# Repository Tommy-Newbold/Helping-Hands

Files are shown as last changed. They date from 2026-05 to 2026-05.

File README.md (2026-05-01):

Helping Hands are interactive public sculptures that invite people to listen to local stories about climate-adapted futures.

---

helping hands wordmark



---

Each hand senses when it is touched, glows with light, and plays an audio story. The project began as part of *Waters of Leith*, a design project exploring how local knowledge, everyday experience, and public imagination can shape climate adaptation in Leith, Edinburgh.

This repository contains the files needed to make your own Helping Hand: 3D-printable parts, casting tools, wiring notes, firmware, and installation guidance.

---

## What are Helping Hands?

Helping Hands are small, touch-sensitive audio sculptures designed to be installed in public or semi-public places.



They act as **waymarkers**: physical points where community stories, memories, concerns, and hopes can be held, heard, and shared.

When someone holds a hand, it responds with light and sound. Each hand can contain a different voice, story, or message from the future.

---

## Why make them?

Helping Hands are about making local imagination tangible.

They can be used for:

- community engagement
- speculative design workshops
- climate adaptation conversations
- public art installations
- local storytelling projects
- education and participatory research
- playful civic experiments

The project is intentionally open-ended. You can build one as a sculpture, a workshop output, a public installation, or a starting point for your own version.

---

## Features

Tommy chat - 2026-05-01 06 41 29

Current and planned firmware features:

- [x] MicroPython firmware
- [x] Touch sensing
- [x] Audio playback using the JQ6500 MP3 module
- [x] Blue LED pulse when touched
- [x] Direct touch trigger
- [x] Near-sense trigger mode
- [x] Access Point monitor dashboard
- [x] Touch logging
- [x] Touch duration logging
- [x] Day/night behaviour
- [x] Quiet hours
- [x] Optional RTC support for reliable timekeeping
- [ ] Mesh mode for linking multiple hands together
- [ ] Windows/Linux install wizard
- [ ] Improved dashboarding
- [ ] Remote access
- [ ] USB-C battery-management routing
- [ ] Lower-cost electronics version
- [ ] More confirmed print profiles

Confirmed print testing:

- [x] Bambu Lab A1 Mini
- [x] Bambu Lab P1S
- [x] Creality Ender 3
- [ ] More printers wanted!

---

## Overall instructions

Tommy chat - 2026-05-01 06 41 34

The basic build process is:

1. Buy the electronic components.
2. Print the enclosure and internal parts.
3. Cast the hands.
4. Wire the electronics.
5. Flash the ESP32 with MicroPython.
6. Upload the Helping Hands firmware.
7. Add your audio files to the JQ6500 module.
8. Configure the hand.
9. Test touch, audio, lights, and power.
10. Install the hand.

For the full build guide, see:

[`docs/instructions.md`](docs/instructions.md)

For print settings and tuning, see:

[`docs/3d-printing.md`](docs/3d-printing.md)

For enclosure customisation, see:

[`docs/enclosure-customisation.md`](docs/enclosure-customisation.md)

---

## Tools

You will likely need:

- 3D printer
- Soldering iron
- laptop or desktop computer

---

# Parts list

## 3D prints

The printable files are split into a few sets:

| Print set | Description | Link |
|---|---|---|
| Enclosure | Main body, lid, mounts, internal structure |  |
| PCB / wiring carrier | Printable wiring support or internal carrier |  |
| Hand casting tool | Tools for aligning threaded rod and casting hands | |

More detail:

[`docs/3d-printing.md`](docs/3d-printing.md)

---

## Components
For full list see: 

[`docs/shopping-list.md`](docs/shopping-list.md)

### Electronics

| Part | Notes | Link |
|---|---|---|
| ESP32 WROOM dev board | Main controller | Link coming soon |
| JQ6500 MP3 player | Audio playback module | Link coming soon |
| Adafruit BQ25185 solar charger | For solar installs | Adafruit link coming soon |
| DS3231 RTC module | Optional, improves day/night and quiet-hour reliability | Link coming soon |
| 18650 Li-ion cell | Use a reputable protected cell where possible | Link coming soon |
| 3W 8Ω 67mm speaker driver | Main audio output | Link coming soon |
| 24 LED COB WS2812B Light Ring | Light feedback | Adafruit / cheap link coming soon |

---

# Firmware

The firmware is written in MicroPython.

Current files include:

| File | Description |
|---|---|
| `main.py` | Main Helping Hands firmware |
| `jq6500.py` | JQ6500 MP3 player library |
| `rtc_flash.py` | RTC setup / flashing helper |
| `config.py.example` | Example configuration file |

---

# Customisation

This project is meant to be messed with. You can customise:

- enclosure form
- textures and surface details
- light behaviour
- timing
- audio content
- installation context
- overall theme

See:

[`docs/enclosure-customisation.md`](docs/enclosure-customisation.md)

---

# Installation

Helping Hands can be installed indoors, outdoors, or as part of temporary public engagement events.

Before installing in public, consider:

- permission from the site owner
- weather protection
- safe mounting
- battery access
- charging method
- audio volume
- trip hazards
- sharp edges
- vandal resistance
- how people will know what to do
- whether the hand needs a plaque, label, or prompt

Suggested prompt:

> Hold my hand. Hear my story.

---

# Documentation

Planned documentation:

| Document | Status |
|---|---|
| `docs/instructions.md` | In progress |
| `docs/3d-printing.md` | In progress |
| `docs/wiring.md` | In progress |
| `docs/firmware.md` | In progress |
| `docs/enclosure-customisation.md` | In progress |
| `docs/casting.md` | In progress |
| `docs/installing.md` | In progress |
| `docs/troubleshooting.md` | In progress |

---

# Troubleshooting

Common issues currently include:

| Problem | Likely cause |
|---|---|
| Touch works on USB but not battery | Weak ground reference or touch threshold needs tuning |
| LEDs do not turn on | Power issue, wrong data pin, or insufficient current |
| Audio does not play | JQ6500 file indexing or wiring issue |
| Time-based features are wrong | RTC not set or missing |
| Dashboard does not appear | ESP32 AP mode not active |
| Touch is too sensitive | Threshold too low |
| Touch is not sensitive enough | Threshold too high or poor touch connection |

See:

[`docs/troubleshooting.md`](docs/troubleshooting.md)

---

# Roadmap

Things I would like to improve next:

- [ ] Better installation wizard
- [ ] Cleaner dashboard UI
- [ ] Mesh behaviour between multiple hands
- [ ] Easier audio upload process
- [ ] Better battery monitoring
- [ ] More reliable solar version
- [ ] Cheaper electronics version
- [ ] More enclosure variants
- [ ] More mounting options
- [ ] More print profiles from different printers
- [ ] Better documentation for public installs

---

# Contributing

Please contribute!

This project is still developing, and there are lots of ways to help:

- build your own version
- share photos of your installation
- test the print files on different printers
- suggest better components
- improve the firmware
- report bugs
- improve the documentation
- make new enclosure variants
- adapt the project for another place or community

If something does not work, open an issue and describe:

1. what you were trying to do
2. what happened
3. what hardware you used
4. what firmware version you used
5. photos or screenshots if useful

Pull requests are welcome, especially for small fixes, documentation improvements, and tested hardware changes.

Forks, remixes, and strange versions are encouraged.

---

# Credits

Created by **Tommy Newbold / Studio Tommy** as part of the *Waters of Leith* project.

This project uses the `jq6500.py` library for controlling the JQ6500 MP3 module.

Credit and source link to be added.

---

# Licensing

This project uses separate licences for code and physical/documentation files.

1. **Code:** Licensed under [GPLv3](https://www.gnu.org/licenses/gpl-3.0.html).
2. **3D Models and Documentation:** Licensed under [CC-BY-SA 4.0](https://creativecommons.org/licenses/by-sa/4.0/).

This means you can use, adapt, remix, and share the project, but improvements should remain open and credited.

---

# A note on AI-assisted code

Some of the firmware and documentation for this project has been developed with the help of AI coding tools.

That means the code should be treated like any other experimental open-source hardware project: useful, hackable, and worth checking carefully before relying on it.

If you spot something odd, inefficient, unsafe, or just badly explained, please open an issue or suggest an improvement.

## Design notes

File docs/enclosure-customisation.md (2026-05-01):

# Enclosure Customisation

This guide covers simple ways to customise the Helping Hands enclosure, from surface decoration and painting to adding custom texture using displacement tools.

The enclosure has been designed to be adaptable. You can keep it plain, paint it, decorate it for a specific project, or generate a textured version for a more site-specific build.

---

## Quick overview

Common customisation options include:

- Painting the enclosure
- Adding project-specific decoration
- Using coloured or translucent filament
- Adding vinyl graphics or labels
- Adding physical props or attachments
- Applying custom surface texture with displacement

For the main build guide, see:

[`docs/instructions.md`](./instructions.md)

For print settings, see:

[`docs/3d-printing.md`](./3d-printing.md)

---

<details open>
<summary><strong>1. Simple decoration</strong></summary>

## 1. Simple decoration

The simplest way to customise the enclosure is through decoration.

For example, in the original urban flooding project, the enclosure was styled with visual references to **life rings**, public safety equipment, and civic infrastructure.

### Ideas

You could customise the enclosure with:

- Painted colour bands
- Vinyl lettering
- Warning-style graphics
- Project logos
- Local place names
- Numbered wayfinding labels
- Small plaques
- Reflective tape
- Weathering or ageing effects
- Attached props or symbolic objects

### Keep it functional

When decorating the enclosure, avoid covering:

- Speaker openings
- Cable holes
- Screw holes
- Key switch access
- LED diffusion areas
- Mounting slots
- Any areas that need to seal cleanly

</details>

---

<details open>
<summary><strong>2. Painting the enclosure</strong></summary>

## 2. Painting the enclosure

The enclosure can be painted if you want a specific finish or colour scheme.

### Basic painting process

1. Lightly sand the surface
2. Clean off dust and grease
3. Use a plastic-compatible primer
4. Apply thin coats of paint
5. Let each coat dry fully
6. Add a clear coat if needed

### Notes for translucent prints

If you are using translucent PET-G for the lighting effect, avoid painting areas where you want light to pass through.

You can also mask parts of the enclosure so that only selected areas glow.

</details>

---

<details open>
<summary><strong>3. Adding custom surface texture with BumpMesh</strong></summary>

## 3. Adding custom surface texture with BumpMesh

For customising the outside body texture, check out the open source tool:

[BumpMesh](https://bumpmesh.com)

BumpMesh lets you apply bump maps and displacement textures to 3D models. This can be used to give the enclosure a custom surface pattern before printing.

### Best use cases

BumpMesh is useful for adding:

- Subtle surface grain
- Project-specific patterns
- Topographic textures
- Water ripple textures
- Fabric-like texture
- Civic or architectural surface references
- Decorative patterns that help hide layer lines

### Recommended approach

You will usually get the best results by:

1. Applying textures to individual walls rather than the whole model at once
2. Keeping the texture subtle
3. Using textures on surfaces that are perpendicular to the build plate
4. Using cylindrical projection mapping where appropriate
5. Testing on a small sample before printing the full enclosure

### Why perpendicular walls work best

Textures tend to print most cleanly when they are on vertical walls.

This is because the printer can build the displacement detail gradually in the layer lines, rather than trying to resolve it across flat top surfaces.

### Cylindrical projection mapping

For rounded enclosure bodies, cylindrical projection mapping can help the texture wrap more naturally around the form.

This is especially useful if you want a continuous pattern around the outside of the enclosure.

</details>

---

## Customisation checklist

Before printing or installing a customised enclosure, check:

- [ ] Decoration does not block the speaker
- [ ] Decoration does not block the key switch
- [ ] Decoration does not block mounting holes
- [ ] Paint does not prevent the enclosure from closing
- [ ] Paint does not cover areas that need to glow
- [ ] Texture is not too deep for reliable printing
- [ ] Textured surfaces have been test printed
- [ ] Mounting and sealing surfaces are still flat
- [ ] The final enclosure still feels appropriate for public interaction

---

## Notes

Customisation should support the purpose of the hand.

A good enclosure design should still feel:

- Approachable
- Robust
- Easy to understand
- Safe to touch
- Connected to the place or project it belongs to

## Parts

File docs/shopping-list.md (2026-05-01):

# Shopping List

This is the basic shopping list for building a Helping Hand. It includes the core electronics, hand casting materials, and general hardware.

> [!NOTE]  
> Links are starting points, not fixed suppliers. AliExpress listings change constantly, so check the photos, dimensions, pinouts, reviews, and delivery times before ordering.

---

## Quick build options

There are two common build routes:

| Build type | Use this if | Main difference |
| --- | --- | --- |
| Indoor / exhibition build | You are making a display hand or prototype | Plaster hand, simpler power setup |
| Outdoor / public build | You need a stronger, more weather-resistant hand | Cold-cast polyurethane hand, better sealing, more robust power |

For the full build process, see:

[`docs/instructions.md`](./instructions.md)

For printing guidance, see:

[`docs/3d-printing.md`](./3d-printing.md)

---

## Electronics

| Part | Notes | Link |
| --- | --- | --- |
| ESP32 WROOM dev board | Main controller. Use a common ESP32-WROOM development board with USB. | [AliExpress search](https://www.aliexpress.com/w/wholesale-ESP32-WROOM-dev-board.html) |
| JQ6500 MP3 player | Audio playback module. Usually loaded over USB Mini. | [AliExpress search](https://www.aliexpress.com/w/wholesale-JQ6500-MP3-player-module.html) |
| Adafruit BQ25185 solar charger | Recommended for solar installs. USB/DC/solar charging with 5V boost output. | [Adafruit product page](https://www.adafruit.com/product/6106) |
| DS3231 RTC module | Optional, but improves day/night and quiet-hour reliability. | [AliExpress search](https://www.aliexpress.com/w/wholesale-DS3231-RTC-module.html) |
| 18650 battery holder | For a removable Li-ion cell. Choose one with leads or a JST connector where possible. | [AliExpress search](https://www.aliexpress.com/w/wholesale-18650-battery-holder-JST.html) |
| 18650 Li-ion cell | Only Purchase Cells from a supplier & producer you know and trust, the supplied link is for the UK | [Nu Battery](https://www.nubattery.co.uk/) |
| 3W 8Ω 67mm speaker driver | Main audio output. Check the diameter against your printed speaker mount. | [AliExpress search](https://www.aliexpress.com/w/wholesale-3W-8-ohm-67mm-speaker.html) |
| 24 LED COB / NeoPixel ring 67mm OD | Light feedback. Use a 5V addressable RGB ring, WS2812B/NeoPixel compatible. | [AliExpress search](https://www.aliexpress.com/w/wholesale-24-bit-WS2812B-LED-ring-5V.html) |
| Key switch | For turning the hand on/off. Small two-position key switches work well. | [AliExpress search](https://www.aliexpress.com/w/wholesale-small-key-switch-2-position.html) |
| Waterproof USB-C connector | For external charging. | [AliExpress search](https://www.aliexpress.com/w/wholesale-waterproof-USB-C-panel-mount-connector.html) |

Optional BMS if solar is not required:

| 1S Li-ion charger/protection board with 5V boost | Cheaper non-solar power option. Often sold as an 18650 charger/protection/boost module. | [AliExpress search](https://www.aliexpress.com/w/wholesale-18650-lithium-battery-charger-protection-5V-boost-module.html) |

### Electronics buying notes

- Check voltage carefully. Most of the system expects **5V power**.
- Check connector types before ordering battery holders and charger boards.
- Avoid very cheap 18650 cells with unrealistic capacity claims.
- Buy a few spare ESP32 boards, LED rings, and small modules if budget allows.
- The cheap non-solar power board should be for a **single-cell Li-ion / 18650 setup** with charging, protection, and 5V boost.
- “BMS board with 5V buck” is probably better written as **1S Li-ion charger/protection board with 5V boost**, because a single 18650 needs to be boosted up to 5V.

---

## Hand casting materials

There are two hand-making routes:

1. Plaster hand
2. Cold-cast polyurethane hand

A plaster hand is cheaper and suitable for indoor use or protected displays. A cold-cast hand is stronger and more suitable for outdoor or public-facing installs.

---

### For plaster hands

| Material | Notes | Link |
| --- | --- | --- |
| Alginate | For making the hand mould. Around 500g per hand is a useful starting point. | [AliExpress search](https://www.aliexpress.com/w/wholesale-alginate-life-casting.html) |
| Herculite plaster | Strong casting plaster. Herculite 2 or similar is recommended. | [AliExpress search](https://www.aliexpress.com/w/wholesale-Herculite-2-plaster.html) |
| M5 threaded rod | Embedded mounting point. Cut to length before casting. | [AliExpress search](https://www.aliexpress.com/w/wholesale-M5-threaded-rod-stainless-steel.html) |
| Mixing cups / tubs | For alginate and plaster. Use containers you do not mind ruining. | [AliExpress search](https://www.aliexpress.com/w/wholesale-disposable-mixing-cups-resin.html) |
| Mixing sticks | Disposable sticks are useful. | [AliExpress search](https://www.aliexpress.com/w/wholesale-wooden-mixing-sticks.html) |
| Gloves | Strongly recommended. | [AliExpress search](https://www.aliexpress.com/w/wholesale-nitrile-gloves.html) |

---

### For cold-cast “metal” hands

| Material | Notes | Link |
| --- | --- | --- |
| Alginate | For the original hand mould. | [AliExpress search](https://www.aliexpress.com/w/wholesale-alginate-life-casting.html) |
| Herculite plaster | For the master / test casts. | [AliExpress search](https://www.aliexpress.com/w/wholesale-Herculite-2-plaster.html) |
| M5 threaded rod | Embedded mounting point. | [AliExpress search](https://www.aliexpress.com/w/wholesale-M5-threaded-rod-stainless-steel.html) |
| Brush-on silicone | For reusable moulds. Smooth-On Rebound 25 or similar. | [AliExpress search](https://www.aliexpress.com/w/wholesale-brush-on-silicone-rubber-mould-making.html) |
| Atomised aluminium powder | For the cold-cast metal effect. Other atomised metals can also be used. | [AliExpress search](https://www.aliexpress.com/w/wholesale-atomized-aluminium-powder-resin-casting.html) |
| Polyurethane resin | Final cast material. A short pot-life resin works, but move quickly. | [AliExpress search](https://www.aliexpress.com/w/wholesale-polyurethane-casting-resin.html) |
| Gloves and respirator | Follow resin safety guidance. | [AliExpress search](https://www.aliexpress.com/w/wholesale-organic-vapour-respirator-resin.html) |

> [!WARNING]  
> Resin, silicone, metal powders, and solvents can be hazardous. Follow the manufacturer’s safety guidance, work with ventilation, and use appropriate PPE.

---

## Other hardware and consumables

| Part | Notes | Link |
| --- | --- | --- |
| 147mm gasket | For the enclosure seal. Confirm size against your enclosure version. | [AliExpress search](https://www.aliexpress.com/w/wholesale-147mm-rubber-gasket.html) |
| Jubilee clips / screws | For mounting to poles, railings, or street furniture. | [AliExpress search](https://www.aliexpress.com/w/wholesale-jubilee-hose-clamps-stainless-steel.html) |
| Wall plugs / anchors | Depends on installation site. | [AliExpress search](https://www.aliexpress.com/w/wholesale-wall-plugs-screws-assortment.html) |
| Heat shrink | For safer wiring and strain relief. | [AliExpress search](https://www.aliexpress.com/w/wholesale-heat-shrink-tubing-assortment.html) |
| Silicone sealant | Optional. Use carefully so the enclosure can still be serviced. | [AliExpress search](https://www.aliexpress.com/w/wholesale-clear-silicone-sealant-waterproof.html) |
| Labels / plaque | For storyteller identity and interaction prompt. | [AliExpress search](https://www.aliexpress.com/w/wholesale-small-engraved-metal-plaque.html) |
| Patience | Not optional. | — |

---

## Minimum useful kit

If you are just trying to get one hand working on the bench, start with:

- ESP32 WROOM dev board
- JQ6500 MP3 module
- Speaker
- LED ring
- DS3231 RTC module
- 18650 holder
- Power board
- 18650 cell
- Key switch
- Copper tape
- Flexible wire
- One plaster hand

You can add the cold-cast hand, waterproof connector, solar charging, and final mounting hardware later.

---

## Buying checklist

### Electronics

- [ ] ESP32 WROOM dev board
- [ ] JQ6500 MP3 player
- [ ] Power board: BQ25185 or cheaper 5V boost option
- [ ] 18650 battery holder
- [ ] 18650 Li-ion cell
- [ ] 3W 8Ω speaker
- [ ] 24 LED ring
- [ ] Key switch
- [ ] USB Mini cable
- [ ] DS3231 RTC module
- [ ] Copper tape
- [ ] Flexible wire

### Optional / install-dependent electronics

- [ ] Waterproof USB-C connector
- [ ] Solar panel, if using the BQ25185 for solar charging
- [ ] Spare JST connectors
- [ ] Spare header pins

### Casting

- [ ] Alginate
- [ ] Herculite plaster
- [ ] M5 threaded rod
- [ ] Mixing cups
- [ ] Mixing sticks
- [ ] Gloves

### Cold casting

- [ ] Brush-on silicone
- [ ] Atomised aluminium powder
- [ ] Polyurethane resin
- [ ] Respirator / PPE

### Installation

- [ ] 147mm gasket
- [ ] Jubilee clips or screws
- [ ] Wall plugs / anchors
- [ ] Heat shrink
- [ ] Silicone sealant
- [ ] Plaque or label

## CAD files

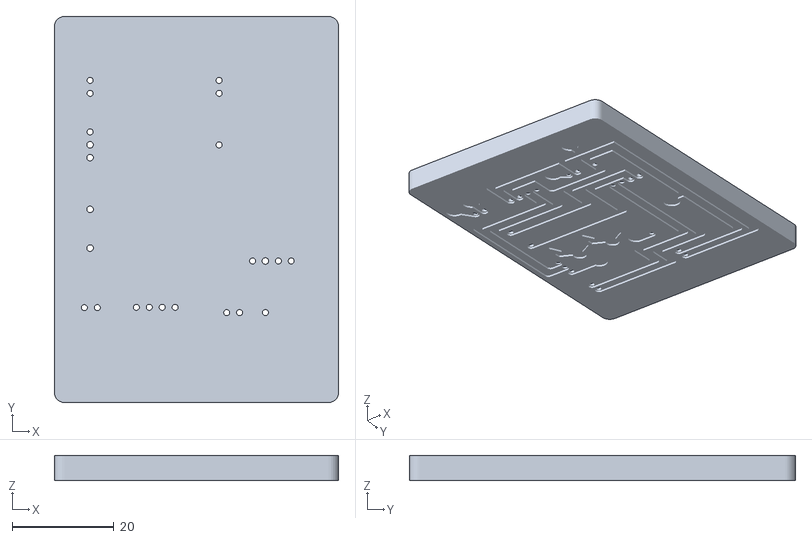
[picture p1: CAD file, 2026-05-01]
3d Files/PCB.stl
56.0 x 76.0 x 5.00

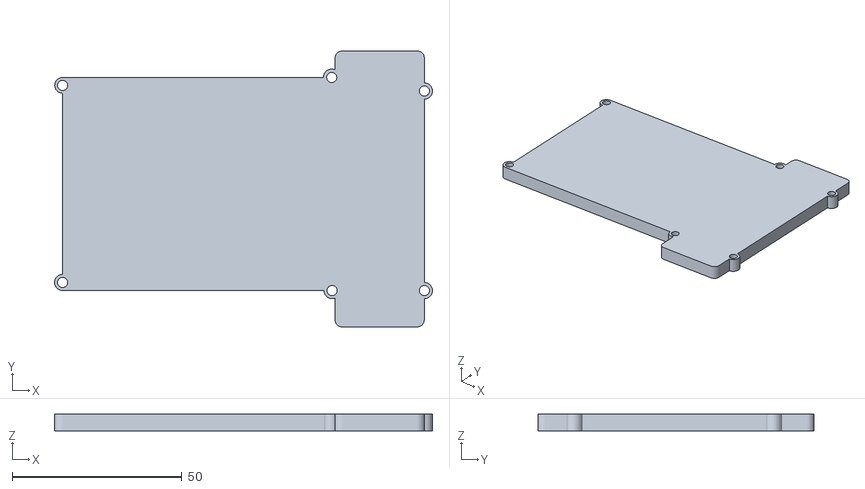
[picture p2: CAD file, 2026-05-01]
3d Files/Inner Lid.stl
111.4 x 81.3 x 5.00

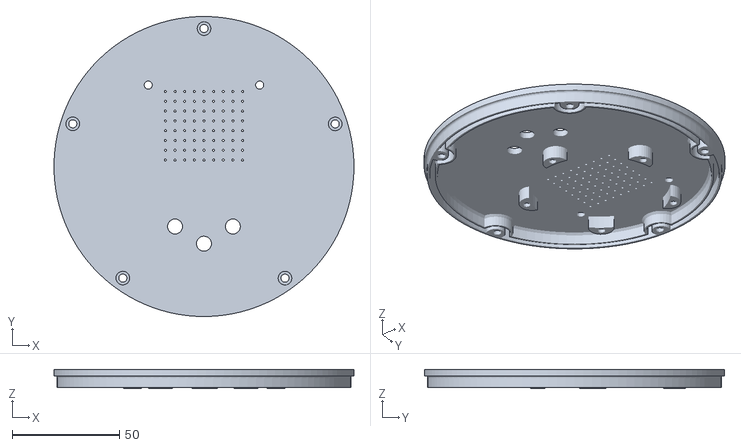
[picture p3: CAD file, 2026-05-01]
3d Files/Outer Lid.stl
140.0 x 140.0 x 9.00

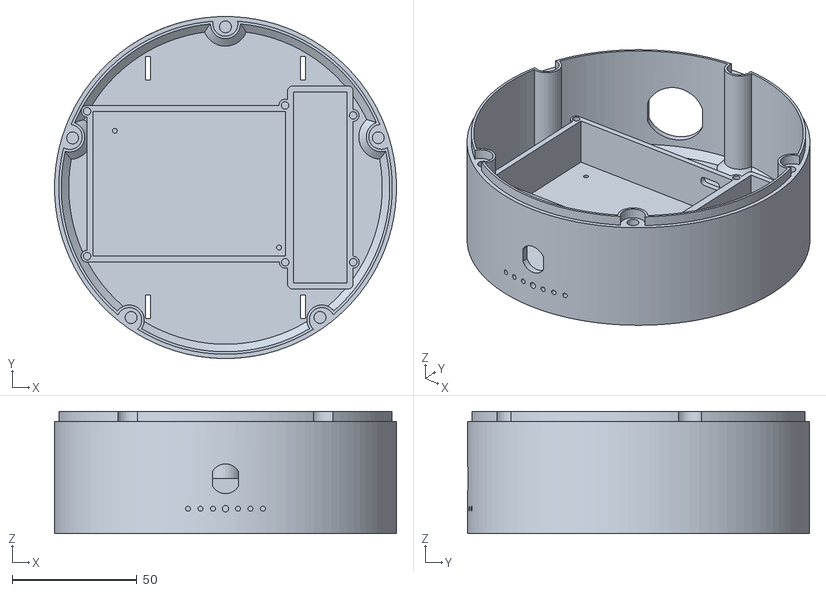
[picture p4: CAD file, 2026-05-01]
3d Files/Enclosure.stl
137.0 x 137.0 x 49.0

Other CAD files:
3d Files/Full Parametric Assembly.f3z

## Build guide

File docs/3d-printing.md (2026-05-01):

# 3D Printing Guide

This guide covers the recommended printing approach for the Helping Hands enclosure, internal parts, LED/speaker assembly, and 3D printed PCB-style carrier board.

For the best lighting effect and strength, print the visible enclosure parts in **translucent PET-G**.

> [!IMPORTANT]  
> Translucent PET-G must be thoroughly dried before printing. Wet PET-G will print weaker, cloudier, stringier, and less cleanly.

---

## Quick print summary

 
 


| Setting / requirement | Recommendation |
| --- | --- |
| Material | Translucent PET-G |
| Nozzle size | 0.4mm |
| Minimum bed size | 150mm × 150mm |
| Filament drying | At least 8 hours before printing |
| Main goal | Strength, translucency, and clean light diffusion |
| Recommended profile | [Print Glass by Dennis Lenz on MakerWorld](https://makerworld.com/en/models/560963-print-glass#profileId-480277) |

The print settings used across the build are based on the MakerWorld **Print Glass** profile by **Dennis Lenz**.

Credit:  
[Print Glass — Dennis Lenz, MakerWorld](https://makerworld.com/en/models/560963-print-glass#profileId-480277)

---

<details open>
<summary><strong>1. Before printing</strong></summary>

## 1. Before printing

### 1.1 Print bed size

All parts have been designed to fit on a **150mm × 150mm** print bed.

This means the parts should fit on smaller printers such as:

- Bambu Lab A1 mini
- Bambu Lab P1S
- Creality Ender 3
- Similar printers with at least a 150mm × 150mm usable print area

### 1.2 Dry the filament

Dry translucent PET-G for at least **8 hours** before printing.

Wet PET-G will reduce:

- Strength
- Clarity
- Surface quality
- Layer bonding
- Light transmission

### 1.3 How to tell if PET-G is wet

Wet PET-G often makes a **popping, snapping, or crackling sound** while extruding.

Good, dry PET-G should extrude smoothly and quietly.

If the print is poor, check these three things first:

1. Dry the filament again
2. Wash the build plate
3. Slow the print down

> [!TIP]  
> When in doubt: dry the filament, clean the plate, and print slower.

</details>

---

<details open>
<summary><strong>2. Recommended slicer profile</strong></summary>

## 2. Recommended slicer profile

The recommended starting point is the MakerWorld profile:

[Print Glass by Dennis Lenz](https://makerworld.com/en/models/560963-print-glass#profileId-480277)

Use that profile directly where possible.

### 2.1 Why use a “glass” PET-G profile?

The Helping Hand enclosure benefits from translucent PET-G because it:

- Diffuses the internal light
- Allows the blue glow to show through the body
- Gives the enclosure a softer, more object-like quality
- Provides better toughness than PLA
- Is more suitable for repeated handling and semi-public installation

### 2.2 Manual slicing fallback

If you cannot use the MakerWorld profile directly, use the settings below as a manual starting point.

> [!NOTE]  
> These are fallback settings, not a replacement for the linked MakerWorld profile. Always test with your own filament and printer.

| Setting | Suggested starting point |
| --- | --- |
| Nozzle | 0.4mm |
| Layer height | 0.1mm–0.2mm |
| Line Width | 0.5-0.6mm|
| Nozzle temperature | 260c-270c |
| Bed temperature | 65-70c |
| Print speed | 20-30mm/s on all walls |
| Cooling | 0 - 20%  |
| Top layers | 0, where the profile requires glass-like infill exposure |
| Bottom layers | 0, where the profile requires glass-like infill exposure |
| Infill | 100% Aligned Rectalinear |
| Flow rate | 1.01 (slightly higer than you normally would)|
| **Always Print with 5mm Brim** |
### 2.3 What matters most

For this project, the important goals are:

1. Strong layer bonding
2. Clean translucent walls
3. Smooth light diffusion
4. Minimal stringing
5. Reliable fit of mechanical parts

If clarity is poor, print slower and dry the filament again before changing lots of slicer settings.

</details>

---

<details open>
<summary><strong>3. Design-for-printing notes</strong></summary>

## 3. Design-for-printing notes

The parts have been designed with FDM 3D printing in mind.

### 3.1 Bevelled edges

Bevelled edges are used to reduce visible hull lines and make the printed parts feel more finished.

### 3.2 Surface texture

Some surfaces include texture to help hide layer lines and reduce the appearance of print artefacts.

### 3.3 Cut overhangs

Overhangs have been reduced or cut away where possible, especially around bolt heads and fixing points.

### 3.4 Press fits

Press fits are used where possible to reduce extra hardware and make assembly easier.

### 3.5 Brass inserts

Brass heat-set inserts are used where parts need to be assembled and disassembled repeatedly.

This is especially useful for:

- The enclosure
- The inner lid
- The LED/speaker assembly
- Parts that may need servicing later

</details>

---

<details open>
<summary><strong>4. Brass inserts</strong></summary>

## 4. Brass inserts

The enclosure uses both **M3** and **M2** brass heat-set inserts.

Useful reference:

[Instructables: Add Metal Threads to Your 3D Prints](https://www.instructables.com/Add-Metal-Threads-to-Your-3D-Prints-Make-Them-Func/)

---

### 4.1 Insert count

The current build uses:

| Insert size | Quantity | Location |
| --- | ---: | --- |
| M3 | 5 | Main enclosure fixing points |
| M2 | 6 | Inner lid |
| M2 | 5 | LED/speaker assembly |

Total:

- **5 × M3 inserts**
- **11 × M2 inserts**

---

### 4.2 Installing brass inserts

1. Use a soldering iron with a clean tip
2. Set the insert squarely into the printed hole
3. Heat the insert gently with the soldering iron
4. Press it down slowly as the plastic softens
5. Stop when the insert sits flush with the surface
6. Let the plastic cool before adding screws

> [!CAUTION]  
> Do not force the insert in cold. This can split the print or deform the hole.

### 4.3 Tips for clean inserts

- Use gentle pressure
- Keep the insert straight
- Do not overheat the plastic
- Test with one insert on a failed print if possible
- Let inserts cool fully before assembling

</details>

---

<details open>
<summary><strong>5. Print quality checks</strong></summary>

## 5. Print quality checks

Before assembly, check each printed part carefully.

### 5.1 Enclosure

Check that:

- The main enclosure is not warped
- The lid fits cleanly
- Screw holes are open
- Brass insert holes are clean
- The hand mounting area is flat and strong
- The key switch hole is clean
- Cable holes are clear

### 5.2 Internal parts

Check that:

- The board carrier fits inside the enclosure
- The battery holder fits
- The LED/speaker assembly fits
- The LED ring sits correctly
- The speaker is not blocked
- The internal lid closes without crushing wires

### 5.3 3D printed PCB-style board

Check that:

- Trace channels are clean
- Copper tape can sit flat in the traces
- Header pin holes are clear
- There are no blobs or strings between traces
- The board is flat enough to solder onto

### 5.4 Alignment tool

Check that:

- The M5 threaded rods fit cleanly
- The rods sit square
- The spacing matches the enclosure
- The tool is strong enough to hold the rods while casting

</details>

---

<details open>
<summary><strong>6. Optional finishing</strong></summary>

## 6. Optional finishing

The printed parts can be used straight from the printer, but there are optional finishing steps.

### 6.1 Light flame polishing

You can very lightly pass a blowtorch over the outside of the translucent PET-G parts to improve clarity.

This can slightly smooth the outer surface and make the print appear clearer.

> [!WARNING]  
> Flame polishing is risky. It is easy to deform the model, burn the surface, or release unpleasant fumes. Only do this in a well-ventilated area, away from flammable materials, and do not breathe the fumes.

### 6.2 Go very lightly

If you try flame polishing:

1. Use a small flame
2. Keep the flame moving
3. Do not hold heat in one place
4. Test on a failed print first
5. Stop before the part visibly softens

This step is optional. A clean, slow, dry PET-G print is more important than finishing.

</details>

---

## Troubleshooting

### The print is cloudy

Likely causes:

- Wet filament
- Printing too fast
- Too much cooling
- Too low nozzle temperature
- Poor flow calibration

Try:

1. Dry the filament again
2. Increase temperature within the filament manufacturer’s range
3. Slow the print down
4. Reduce cooling
5. Check flow calibration

### The print is weak

Likely causes:

- Wet filament
- Low nozzle temperature
- Poor layer bonding
- Too much cooling
- Under-extrusion

Try:

1. Dry the filament again
2. Increase nozzle temperature within the safe PET-G range
3. Reduce fan speed
4. Check extrusion and flow
5. Print slower

### The print will not stick

Likely causes:

- Dirty build plate
- Incorrect bed temperature
- Poor first layer height
- Damp filament

Try:

1. Wash the build plate
2. Re-level or recalibrate the printer
3. Check first layer squish
4. Dry the filament
5. Use the correct plate settings for PET-G

### The print is stringy

Likely causes:

- Wet filament
- Too high temperature
- Retraction not tuned
- Travel moves too slow

Try:

1. Dry the filament
2. Tune temperature
3. Tune retraction
4. Increase travel speed if appropriate

---

## Final print checklist

Before moving on to assembly, check:

### Printing

- [ ] Translucent PET-G used
- [ ] Filament dried for at least 8 hours
- [ ] 0.4mm nozzle used
- [ ] Parts printed cleanly
- [ ] No major warping
- [ ] No major cracking or delamination
- [ ] All parts fit on the intended 150mm × 150mm bed

### Fit and finish

- [ ] Enclosure closes properly
- [ ] Lid fits
- [ ] Board carrier fits
- [ ] Battery holder fits
- [ ] LED/speaker assembly fits
- [ ] Cable holes are clear
- [ ] Mounting slots are clear

### Inserts and hardware

- [ ] 5 × M3 inserts installed
- [ ] 11 × M2 inserts installed
- [ ] Screws thread cleanly
- [ ] Inserts are flush
- [ ] No melted or distorted fixing points

### Ready for assembly

- [ ] 3D printed PCB traces are clean
- [ ] Alignment tool works with M5 threaded rods
- [ ] Enclosure is ready for electronics
- [ ] Hand mounting area is ready

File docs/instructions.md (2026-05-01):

# Helping Hands Build Instructions

This guide walks through the full process of building a Helping Hand: buying parts, printing the enclosure, casting the hand, wiring the electronics, flashing the firmware, adding audio, testing the system, and installing it.

> [!IMPORTANT]  
> Read the whole guide before starting. Some steps, especially casting and wiring, are much easier if you plan ahead.

---

## Build overview

The basic build process is:

1. Buy the electronic components  
   See [`docs/shopping_list.md`](./shopping_list.md)

2. Print the enclosure and internal parts  
   See the MakerWorld model page and [`docs/3d_printing.md`](./3d_printing.md)

3. Cast the hand  
   Choose either a plaster hand or a polyurethane cold cast hand.

4. Wire the electronics

5. Flash the ESP32 with MicroPython  
   See the official [MicroPython ESP32 getting started guide](https://docs.micropython.org/en/latest/esp32/tutorial/intro.html)

6. Upload the Helping Hands firmware

7. Add your audio files to the JQ6500 module

8. Test touch, audio, lights, and power

9. Install the hand

---

## Before you begin

### What kind of hand should I make?

There are two final hand types:

| Hand type | Best for | Notes |
| --- | --- | --- |
| Plaster hand | Indoor use, exhibitions, protected installations, low-cost prototypes | Cheaper and easier to make |
| Polyurethane cold cast hand | Outdoor use, public installation, more durable builds | Stronger and more weather-resistant |

> [!NOTE]  
> To make a cold cast hand, you must first make a plaster hand. The plaster hand becomes the master used to make the silicone mould.

### Useful links

- [MicroPython ESP32 getting started guide](https://docs.micropython.org/en/latest/esp32/tutorial/intro.html)
- [`mpremote` on PyPI](https://pypi.org/project/mpremote/)
- [Thonny Python IDE](https://thonny.org/)
- [Instructables: Lifecasting Hands](https://www.instructables.com/Lifecasting---hands/)
- [Smooth-On: Moulding a 3D object with Rebound 25](https://www.smooth-on.com/tutorials/molding-3-object-rebound-25-brush-silicone-rubber/)

---

<details>
<summary><strong>1. Buy the electronic components</strong></summary>

## 1. Buy the electronic components

Buy the required electronic components before printing and casting so you can test-fit parts as you go.

See:

[`docs/shopping_list.md`](./shopping_list.md)

### Core components

The exact list may change between versions, but the core system includes:

- ESP32 development board
- JQ6500 audio module
- Audio driver / amplifier
- Speaker
- RTC module
- BQ25185 battery / charging board
- Li-ion battery
- NeoPixel / addressable RGB LED ring
- Key switch
- JST connectors
- Copper tape
- Header pins
- Wire
- M3 and M5 hardware

</details>

---

<details>
<summary><strong>2. Print the enclosure and internal parts</strong></summary>

## 2. Print the enclosure and internal parts

Print the enclosure, internal mounts, alignment tools, and 3D printed PCB-style carrier board.

See:

[`docs/3d_printing.md`](./3d_printing.md)

Also check the MakerWorld model page when available.

### Recommended print checks

Before moving on, check that:

- The enclosure closes properly
- The board fits inside the enclosure
- The battery holder fits
- The LED ring fits
- The mounting slots are clear
- The threaded rod alignment tool prints cleanly
- The 3D printed PCB trace channels are clean and usable

### Notes

Printing profiles have been tested on:

- Bambu Lab A1 mini
- Bambu Lab P1S
- Creality Ender 3

More printer profiles are welcome.

</details>

---

<details open>
<summary><strong>3. Cast the hand</strong></summary>

## 3. Cast the hand

You can make either:

- A plaster hand
- A polyurethane and atomised metal powder cold cast hand

The plaster hand is the simpler version. The cold cast hand is stronger and more suitable for outdoor/public use.

---

### 3.1 Casting a plaster hand

You can either:

- Buy a life casting hand kit and follow the kit instructions
- Or buy around **500g of alginate per hand** and a strong casting plaster such as **Herculite 2**

For the basic hand casting process, follow:

[Instructables: Lifecasting Hands](https://www.instructables.com/Lifecasting---hands/)

Or follow the instructions provided with your casting kit.

#### While the plaster is setting

Before the plaster cures, insert both the touch sensing wires and the mounting rods.

##### Add touch sensing wires

Insert **4 wires** into the hand, reaching into the fingers.

These wires improve touch sensing reliability by increasing the conductive area inside the hand.

Prepare each wire like this:

1. Strip around **80%** of the wire that will sit inside the plaster
2. Leave a small amount of sheathing inside the plaster so the wire is mechanically held
3. Leave around **100mm** of wire hanging out from the base of the hand

These wires will later connect to the capacitive touch sensing lead.

##### Add mounting rods

Insert **two 150mm lengths of M5 threaded rod** into the alignment tool, then set them into the plaster.

These rods align the hand with the enclosure and provide the mechanical fixing points.

#### Cure and finish the plaster hand

Once the plaster has cured enough to remove:

1. Carefully remove the hand from the alginate mould
2. Leave the plaster hand to fully dry and cure for at least **48 hours**
3. Sand, paint, or finish the hand if desired

Your plaster hand is now finished.

> [!TIP]  
> Have fun with different hand poses. The best Helping Hands have character: an inviting grip, a soft hold, or a slightly strange little personality.

---

### 3.2 Making a cold cast hand

To make a cold cast hand, start with a fully dried plaster hand.

You can skip setting wires and threaded rods into this plaster hand, because it will be used as the master for the silicone mould. The wires and rods will be added to the final polyurethane hand later.

#### Make the silicone mould

1. Take your dried plaster hand
2. Hot glue it to a board you do not care about
3. Use a brush-on silicone such as **Smooth-On Rebound 25**
4. Build up the mould in layers, following Smooth-On’s instructions
5. Allow the mould to fully cure

Useful reference:

[Smooth-On: Moulding a 3D object with Rebound 25](https://www.smooth-on.com/tutorials/molding-3-object-rebound-25-brush-silicone-rubber/)

#### Mix the cold cast resin

Use:

- 10-minute polyurethane resin
- Atomised aluminium powder, or another atomised metal powder of your choice

Mix at a ratio of roughly:

```txt
1 part resin : 3 parts metal powder
```

The mixture will be thick.

Start with a small batch. Around **60g** is usually enough for the first coat on a large male hand.

#### Cast the hollow shell

1. Pour the first resin/metal mix into the mould
2. Rotate the mould constantly so the resin coats every surface
3. Keep rotating for around **5 minutes**, or until the resin starts to set and no longer drips
4. Repeat immediately with another batch
5. Build up **3–4 coats** until you have a strong hollow hand

#### Add wires and mounting rods

Once the hollow hand has been formed:

1. Insert the touch sensing wires into the fingers
2. Insert the M5 threaded rods using the alignment tool
3. Fix everything in place with a final batch of resin

You do not need to add metal powder to this final internal fixing pour.

#### Finish the cold cast hand

Once cured:

1. Demould carefully
2. Trim or sand any rough edges
3. Polish the surface with a metal polish such as Autosol, if desired

The cold cast hand should now have a metallic surface, a strong shell, embedded sensing wires, and mounting rods ready for installation.

</details>

---

<details open>
<summary><strong>4. Wire the electronics</strong></summary>

## 4. Wire the electronics

The Helping Hand uses a 3D printed PCB-style carrier board with copper tape traces.

Work slowly. The board is simple, but it is easy to lift copper tape or accidentally create shorts.

> [!WARNING]  
> Always solder with ventilation or extraction. Avoid breathing solder fumes or melted plastic fumes.

---

### 4.1 Prepare the 3D printed PCB

1. Lay copper tape over all the printed traces
2. Gently press the tape into the trace channels  
   A cotton bud tip works well
3. Sand away the extra copper tape using 400 grit sandpaper or an orbital sander
4. Keep sanding until only the intended copper traces remain
5. Check carefully for shorts between traces

Go gently. If you sand too far and rip off a trace, either:

- Replace it with a precisely cut piece of copper tape
- Or jump the broken trace with a wire

---

### 4.2 Add header pins

1. Place PTH header pins into the board from the non-tape side
2. Solder each joint onto the copper tape
3. Heat the pin, not the tape
4. Let the solder flow onto the copper

> [!CAUTION]  
> Do not overheat the copper tape. The plastic board can melt.

---

### 4.3 Add the components

Place the components in their marked positions and solder them to the board.

The exact layout depends on your board version, but the core modules are:

- ESP32
- JQ6500 audio module
- BQ25185 battery / charging board
- RTC module
- Audio driver / amplifier
- LED ring connections
- Touch sensing lead
- Key switch connections
- Battery connector

---

### 4.4 Wire through the enclosure

Through the holes in the bottom of the enclosure:

| Connection | Wire to |
| --- | --- |
| Key switch | GND and EN on the BQ25185 |
| Sensing lead | D4 |
| LED ring GND | GND |
| LED ring power | 5V |
| LED ring data | D27 |
| Audio driver power | JQ6500 / audio power pads |
| Battery enclosure | BQ25185 via JST connector |

Install the board and battery into the enclosure.

For easy disassembly, use a small terminal block or WAGO connector between the hand’s sensing wires and the main sensing lead.

</details>

---

<details open>
<summary><strong>5. Flash and upload the firmware</strong></summary>

## 5. Flash and upload the firmware

The Helping Hand firmware runs on MicroPython.

---

### 5.1 Flash MicroPython to the ESP32

Flash the ESP32 with MicroPython using the official guide:

[MicroPython ESP32 tutorial](https://docs.micropython.org/en/latest/esp32/tutorial/intro.html)

You can use whichever flashing method you prefer, but `esptool.py` is the common route.

Once MicroPython is installed, confirm that you can connect to the board before uploading the Helping Hands files.

---

### 5.2 Choose an upload tool

You can upload files using either:

- [`mpremote`](https://pypi.org/project/mpremote/)
- [Thonny](https://thonny.org/)

Use whichever tool you are most comfortable with.

---

### 5.3 Set the RTC

First upload and run:

```txt
firmware/set_rtc.py
```

This script grabs the current time and date from your computer and writes it to the onboard RTC.

---

### 5.4 Upload the main files

Next upload:

```txt
jq6500.py
main.py
```

Optional settings you may want to tweak in `main.py` include:

- LED brightness
- Touch-on sensitivity
- Touch-off sensitivity
- Pulse speed
- Quiet hours
- Day/night behaviour
- Wi-Fi dashboard name
- Audio behaviour

</details>

---

<details open>
<summary><strong>6. Add audio to the JQ6500 module</strong></summary>

## 6. Add audio to the JQ6500 module

Upload your audio tracks to the JQ6500 module using the JQ6500 upload tool.

### File naming

Format the files like this:

```txt
001 Main story audio, played when touched, up to 60 seconds.mp3
002 Arming sound effect.mp3
003 Wi-Fi connected sound effect.mp3
```

### Audio behaviour

The exact behaviour depends on the firmware version, but the general structure is:

| Track | Use |
| --- | --- |
| `001` | Main voice / story audio |
| `002` | Arming sound effect |
| `003` | Wi-Fi connected sound effect |

Keep the main story track short. Around **30–60 seconds** works well for public interaction.

</details>

---

<details open>
<summary><strong>7. Test the hand</strong></summary>

## 7. Test the hand

Before installation, test the full system.

---

### 7.1 Power on

1. Turn the key switch to power on the hand
2. Wait around **10 seconds** for the touch sensor to calibrate
3. Do not touch the hand during calibration

---

### 7.2 Test the touch interaction

When you hold the hand:

- The hand should light up
- The main audio should start playing

When you let go:

- The audio should stop or pause
- The lights should return to the idle state

If you grab the hand again within around **10 seconds**, the audio should resume from where it left off.

If the hand is left untouched for longer, it should:

- Flash pink
- Play the arming sound
- Restart the main story track the next time it is touched

---

### 7.3 Check the dashboard

To check the dashboard:

1. Connect to the hand’s Wi-Fi network  
   Usually named something like:

```txt
HelpingHand1
```

2. Open a browser and go to:

```txt
http://192.168.4.1
```

From the dashboard you can check:

- Uptime
- System time
- Current state
- Number of touches
- Touch duration
- Recent activity
- Other system metrics

</details>

---

<details open>
<summary><strong>8. Install the hand</strong></summary>

## 8. Install the hand

The enclosure can be mounted in two main ways.

---

### 8.1 Wall mounting

Use **4 M3 screws** through the mounting slots to attach the hand to a wall or flat surface.

---

### 8.2 Pole mounting

Use **2 jubilee clips** to mount the hand to a pole, railing, or similar street furniture.

---

### 8.3 Outdoor notes

For outdoor use:

- Use the cold cast hand
- Check the enclosure is closed properly
- Protect cables from strain
- Consider extra sealing depending on the installation environment
- Avoid placing the speaker or openings where water can pool

</details>

---

## Final checklist

Before calling the build finished, check:

### Printed parts

- [ ] Enclosure printed
- [ ] Internal printed parts complete
- [ ] Board carrier printed
- [ ] Alignment tool printed

### Cast hand

- [ ] Hand cast
- [ ] Touch wires embedded
- [ ] Mounting rods embedded
- [ ] Hand fully cured
- [ ] Hand finished / sealed if needed

### Electronics

- [ ] Copper tape PCB prepared
- [ ] No shorts between traces
- [ ] Components soldered
- [ ] Battery connected
- [ ] Key switch working
- [ ] LED ring connected
- [ ] Speaker connected
- [ ] Touch sensing lead connected

### Firmware and audio

- [ ] ESP32 flashed with MicroPython
- [ ] RTC set
- [ ] Firmware uploaded
- [ ] Audio uploaded to JQ6500
- [ ] Touch sensing tested
- [ ] LED ring tested
- [ ] Audio tested
- [ ] Dashboard tested

### Installation

- [ ] Enclosure closed securely
- [ ] Hand mounted securely
- [ ] Cables protected
- [ ] Outdoor sealing checked, if relevant

Once all of that works, you have a Helping Hand.

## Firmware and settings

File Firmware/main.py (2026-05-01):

from time import ticks_ms, ticks_diff, sleep_ms
from machine import Pin, TouchPad, SoftI2C, UART
from jq6500 import Player
import neopixel
import network
import socket
import ujson
import gc

# =========================================================
# CONFIG
# =========================================================

# --- audio player
p = Player(port=2)
p.set_volume(30)

# --- touch input
TOUCH_PIN = 4
tp = TouchPad(Pin(TOUCH_PIN))

# --- RTC / I2C
I2C_SDA = 21
I2C_SCL = 22
RTC_ADDR = 0x68
RTC_ENABLED = True

# --- NeoPixel
NEO_PIN = 27
NUM_PIXELS = 24
LED_BRIGHTNESS = 0.4
PULSE_PERIOD_MS = 2200
LED_UPDATE_MS = 15

# --- touch tunables
A = 0.2
ON = 0.93
OFF = 0.96
DB_ON = 100
DB_OFF = 100
DRIFT = 0.01
RESTART = 5_000
PRINT_EVERY = 1000

# --- loop timing
LOOP_MS = 10

# --- logging
ENABLE_LOGGING = True
LOG_PATH = "touch_log.csv"
FLUSH_EVERY = 20
SAFETY_FLUSH_MS = 5_000

# --- dashboard / Wi-Fi AP
AP_SSID = "HelpingHand01"
AP_PASSWORD = "handtouch"
HTTP_PORT = 80
RECENT_EVENTS_MAX = 20
PLACEHOLDER_BATTERY_V = 3.92

# --- rolling stats
ROLLING_TOUCH_COUNT = 20

# --- housekeeping
GC_EVERY_MS = 10_000
HTTP_RECV_SIZE = 1024
HTTP_CLIENT_TIMEOUT = 0.15
HTTP_BACKLOG = 4
MAX_HTTP_PER_LOOP = 3

# =========================================================
# RTC HELPERS
# =========================================================

i2c = None
if RTC_ENABLED:
    i2c = SoftI2C(scl=Pin(I2C_SCL), sda=Pin(I2C_SDA), freq=100000)

def bcd_to_dec(b):
    return ((b >> 4) * 10) + (b & 0x0F)

def dec_to_bcd(d):
    return ((d // 10) << 4) | (d % 10)

def rtc_read_datetime():
    if not RTC_ENABLED or i2c is None:
        raise OSError("RTC disabled")
    data = i2c.readfrom_mem(RTC_ADDR, 0x00, 7)
    second = bcd_to_dec(data[0] & 0x7F)
    minute = bcd_to_dec(data[1] & 0x7F)
    hour = bcd_to_dec(data[2] & 0x3F)
    weekday = bcd_to_dec(data[3] & 0x07)
    day = bcd_to_dec(data[4] & 0x3F)
    month = bcd_to_dec(data[5] & 0x1F)
    year = 2000 + bcd_to_dec(data[6])
    return (year, month, day, hour, minute, second, weekday)

def rtc_set_datetime(year, month, day, hour, minute, second, weekday=1):
    if not RTC_ENABLED or i2c is None:
        raise OSError("RTC disabled")
    data = bytes([
        dec_to_bcd(second), dec_to_bcd(minute), dec_to_bcd(hour),
        dec_to_bcd(weekday), dec_to_bcd(day), dec_to_bcd(month),
        dec_to_bcd(year - 2000),
    ])
    i2c.writeto_mem(RTC_ADDR, 0x00, data)

def rtc_iso_string():
    if not RTC_ENABLED:
        return "RTC_DISABLED"
    try:
        y, mo, d, h, mi, s, wd = rtc_read_datetime()
        return "{:04d}-{:02d}-{:02d} {:02d}:{:02d}:{:02d}".format(y, mo, d, h, mi, s)
    except Exception as e:
        print("RTC read error:", e)
        return "RTC_ERROR"

def rtc_epoch_seconds():
    if not RTC_ENABLED:
        return None
    try:
        y, mo, d, h, mi, s, wd = rtc_read_datetime()
    except Exception as e:
        print("RTC read error:", e)
        return None
    mdays = [31,28,31,30,31,30,31,31,30,31,30,31]
    mdays_leap = [31,29,31,30,31,30,31,31,30,31,30,31]
    def is_leap(year):
        return (year % 4 == 0 and year % 100 != 0) or (year % 400 == 0)
    days = 0
    for yr in range(2000, y):
        days += 366 if is_leap(yr) else 365
    month_days = mdays_leap if is_leap(y) else mdays
    for m in range(1, mo):
        days += month_days[m - 1]
    days += (d - 1)
    return days * 86400 + h * 3600 + mi * 60 + s

# =========================================================
# GENERAL HELPERS
# =========================================================

def format_uptime(ms):
    total_s = ms // 1000
    days = total_s // 86400
    total_s %= 86400
    hours = total_s // 3600
    total_s %= 3600
    mins = total_s // 60
    secs = total_s % 60
    return "{}d {}h {}m {}s".format(days, hours, mins, secs)

def format_duration_ms(ms):
    return "{:.2f} s".format(ms / 1000)

def get_state_string(playing, touch_active, armed):
    if playing: return "playing"
    if touch_active: return "touched"
    if armed: return "armed"
    return "idle"

# =========================================================
# NEOPIXEL HELPERS
# =========================================================

np = neopixel.NeoPixel(Pin(NEO_PIN, Pin.OUT), NUM_PIXELS)
_last_led = None
last_led_update = 0

def scale8(x, brightness):
    v = int(x * brightness)
    if v < 0: return 0
    if v > 255: return 255
    return v

def set_all(r, g, b):
    global _last_led
    rr = scale8(r, LED_BRIGHTNESS)
    gg = scale8(g, LED_BRIGHTNESS)
    bb = scale8(b, LED_BRIGHTNESS)
    rgb = (rr, gg, bb)
    if _last_led == rgb:
        return
    for i in range(NUM_PIXELS):
        np[i] = rgb
    np.write()
    _last_led = rgb

def leds_off():
    set_all(0, 0, 0)

def pulse_blue(now_ms):
    phase = now_ms % PULSE_PERIOD_MS
    half = PULSE_PERIOD_MS // 2
    x = (phase / half) if phase < half else ((PULSE_PERIOD_MS - phase) / half)
    eased = x * x * (3.0 - 2.0 * x)
    level = 16 + int(239 * eased)
    set_all(0, level // 6, level)

def update_leds(now_ms, active, client_connected):
    global last_led_update
    if ticks_diff(now_ms, last_led_update) < LED_UPDATE_MS:
        return
    last_led_update = now_ms
    if active:
        # Playing or touch active - blue pulse takes priority
        pulse_blue(now_ms)
    elif client_connected:
        # Steady dim warm white to indicate a device is connected
        set_all(40, 30, 10)
    else:
        leds_off()

def _hsv_to_rgb(h, s, v):
    """Convert HSV (0-255 each) to RGB tuple."""
    if s == 0:
        return (v, v, v)
    h6 = (h * 6) >> 8
    f  = (h * 6) & 0xFF
    p  = (v * (255 - s)) >> 8
    q  = (v * (255 - (s * f >> 8))) >> 8
    t  = (v * (255 - (s * (255 - f) >> 8))) >> 8
    if h6 == 0: return (v, t, p)
    if h6 == 1: return (q, v, p)
    if h6 == 2: return (p, v, t)
    if h6 == 3: return (p, q, v)
    if h6 == 4: return (t, p, v)
    return (v, p, q)

def play_connect_effect():
    """
    Blocking rainbow chase for ~2 s when a client connects.
    Rotates the full hue wheel around the ring twice.
    Ends by settling into steady warm white (client connected indicator).
    """
    DURATION_MS = 2000
    STEP_MS     = 20
    steps       = DURATION_MS // STEP_MS
    for i in range(steps):
        offset = (i * 256 // steps) & 0xFF
        for j in range(NUM_PIXELS):
            hue = (offset + j * 256 // NUM_PIXELS) & 0xFF
            r, g, b = _hsv_to_rgb(hue, 220, 180)
            np[j] = (scale8(r, LED_BRIGHTNESS),
                     scale8(g, LED_BRIGHTNESS),
                     scale8(b, LED_BRIGHTNESS))
        np.write()
        sleep_ms(STEP_MS)
    # Settle into steady warm white — client is still connected
    set_all(40, 30, 10)

def play_armed_effect():
    """
    Blocking pink slow-pulse effect for entering armed state (~1.8 s).
    Pink = high red, medium blue, no green.
    One full breathe-in / breathe-out cycle using smoothstep easing.
    LEDs go dark at the end (armed idle = off).
    """
    STEPS = 60
    STEP_MS = 15
    for i in range(STEPS):
        x = i / (STEPS - 1)
        # smoothstep up then down
        if x < 0.5:
            t = x * 2
        else:
            t = (1.0 - x) * 2
        eased = t * t * (3.0 - 2.0 * t)
        level = int(255 * eased)
        r = level
        g = level // 8          # slight warmth
        b = level // 2          # pink-purple tint
        for j in range(NUM_PIXELS):
            np[j] = (scale8(r, LED_BRIGHTNESS),
                     scale8(g, LED_BRIGHTNESS),
                     scale8(b, LED_BRIGHTNESS))
        np.write()
        sleep_ms(STEP_MS)
    leds_off()

# =========================================================
# LOGGING
# =========================================================

BOOT = ticks_ms()
_log_buf = []
_buf_count = 0
next_flush = BOOT + SAFETY_FLUSH_MS

def ensure_log_header():
    if not ENABLE_LOGGING:
        return
    try:
        with open(LOG_PATH, "r") as f:
            header = f.readline().strip()
            expected = "touch_id,rtc_start,uptime_start_ms,duration_ms,min_ema,armed"
            if header != expected:
                print("WARNING: existing log header differs from expected.")
    except OSError:
        with open(LOG_PATH, "w") as f:
            f.write("touch_id,rtc_start,uptime_start_ms,duration_ms,min_ema,armed\n")

def flush_log():
    global _buf_count
    if (not ENABLE_LOGGING) or (not _log_buf):
        return
    try:
        with open(LOG_PATH, "a") as f:
            f.write("".join(_log_buf))
        _log_buf.clear()
        _buf_count = 0
    except OSError as e:
        print("LOG WRITE ERROR:", e)

def log_touch_event(touch_id, rtc_start, uptime_start_ms, dur_ms, min_ema, armed_flag):
    global _buf_count
    if not ENABLE_LOGGING:
        return
    _log_buf.append("{},{},{},{},{},{}\n".format(
        touch_id, rtc_start, uptime_start_ms, dur_ms, int(min_ema),
        1 if armed_flag else 0
    ))
    _buf_count += 1
    if _buf_count >= FLUSH_EVERY:
        flush_log()

# =========================================================
# AUDIO HELPERS
#
# Key facts about the JQ6500 flash (16P) module:
#   - Flash module never truly "stops" - it goes to PAUSED after a track ends.
#   - p.play() (cmd 0x0D) resumes from paused, which means it restarts
#     from the beginning when the track has finished (position resets).
#   - play_by_index is unreliable from paused/stopped state on flash.
#   - The uart.read() flush inside write_bytes in jq6500.py can leave
#     the UART dirty if called too quickly after a previous command.
#     We flush the UART ourselves before issuing play to stay clean.
# =========================================================

# Raw JQ6500 command frames (bypasses library's uart.read() flush
# which can misalign timing when the module has sent back unsolicited
# status bytes after a track finishes).
_CMD_PLAY      = bytes([0x7E, 0x02, 0x0D, 0xEF])  # resume/play
_CMD_RESET     = bytes([0x7E, 0x02, 0x0C, 0xEF])  # soft reset
_CMD_VOL_30    = bytes([0x7E, 0x03, 0x06, 0x1E, 0xEF])  # volume 30
_CMD_SRC_FLASH = bytes([0x7E, 0x03, 0x09, 0x04, 0xEF])  # source = builtin flash
_CMD_PLAY_IDX2 = bytes([0x7E, 0x04, 0x03, 0x00, 0x02, 0xEF])  # play index 2
_CMD_PLAY_IDX3 = bytes([0x7E, 0x04, 0x03, 0x00, 0x03, 0xEF])  # play index 3

def _uart_drain():
    """
    Properly drain the JQ6500 RX buffer.
    Wait long enough for any in-flight bytes to arrive, then read them all.
    Unlike the library's uart.read() with no args (returns immediately),
    this actually waits for the bus to go quiet.
    """
    sleep_ms(120)
    while p.uart.any():
        p.uart.read()
        sleep_ms(20)

def _raw_write(cmd):
    """Send a raw command frame, bypassing the library's flush-then-write."""
    p.uart.write(cmd)

def reset_track():
    """
    Restart track 1 on the JQ6500 flash module from a clean state.

    Problem: after a track ends naturally the module sends unsolicited
    status bytes. The library's write_bytes() does uart.read() before
    every command, but with no length/timeout this only drains what's
    already arrived — if bytes are still in flight it grabs a partial
    frame and the next command gets dropped silently.

    Solution:
      1. Drain properly (wait + read loop)
      2. Soft-reset the module to guarantee a known state
      3. Wait for reset to complete (500 ms per datasheet)
      4. Re-set source to builtin flash and volume
      5. Send play
    """
    print("DBG reset_track: draining UART")
    _uart_drain()

    print("DBG reset_track: sending soft reset")
    _raw_write(_CMD_RESET)
    sleep_ms(600)          # datasheet says wait ~500 ms after reset

    print("DBG reset_track: setting source + volume")
    _raw_write(_CMD_SRC_FLASH)
    sleep_ms(200)
    _raw_write(_CMD_VOL_30)
    sleep_ms(100)

    print("DBG reset_track: sending play")
    _raw_write(_CMD_PLAY)
    print("DBG reset_track: done")

def play_track_once(cmd):
    """
    Play a specific track by raw index command, bypassing the library.
    Used for effect tracks (armed = track 2, connect = track 3) that
    should play once and leave the module in a known paused state.
    Drains UART first, sends cmd, no wait — caller decides timing.
    """
    _uart_drain()
    _raw_write(_CMD_SRC_FLASH)
    sleep_ms(100)
    _raw_write(_CMD_VOL_30)
    sleep_ms(50)
    _raw_write(cmd)

# =========================================================
# RECENT EVENTS
# =========================================================

recent_events = []

def add_event(msg):
    stamp = rtc_iso_string()
    line = "{} | {}".format(stamp, msg)
    recent_events.append(line)
    if len(recent_events) > RECENT_EVENTS_MAX:
        recent_events.pop(0)
    print("EVENT:", line)

# =========================================================
# DASHBOARD / STATS HELPERS
# =========================================================

recent_touch_durations = []
touch_timestamps_24h = []
audio_play_count = 0
last_touch_time = "Never"

def add_touch_duration(dur_ms):
    recent_touch_durations.append(dur_ms)
    if len(recent_touch_durations) > ROLLING_TOUCH_COUNT:
        recent_touch_durations.pop(0)

def get_avg_touch_duration_ms():
    if not recent_touch_durations:
        return None
    return sum(recent_touch_durations) / len(recent_touch_durations)

def update_24h_touch_window():
    if not RTC_ENABLED:
        return None
    now_s = rtc_epoch_seconds()
    if now_s is None:
        return None
    cutoff = now_s - 86400
    while touch_timestamps_24h and touch_timestamps_24h[0] < cutoff:
        touch_timestamps_24h.pop(0)
    return len(touch_timestamps_24h)

def add_touch_timestamp_24h():
    if not RTC_ENABLED:
        return
    now_s = rtc_epoch_seconds()
    if now_s is None:
        return
    touch_timestamps_24h.append(now_s)
    update_24h_touch_window()

def get_touches_24h_display():
    count = update_24h_touch_window()
    if count is None:
        return "N/A"
    return count

def get_clients_connected():
    try:
        stations = ap.status("stations")
        if not stations:
            return 0
        return len(stations)
    except Exception as e:
        print("stations error:", e)
        return 0

# =========================================================
# DASHBOARD HTML
# =========================================================

def dashboard_html():
    return """<!doctype html>
<html>
<head>
<meta charset="utf-8">
<meta name="viewport" content="width=device-width, initial-scale=1">
<title>Helping Hand</title>
<style>
body{{font-family:Arial,sans-serif;margin:0;padding:16px;background:#f4f4f4;color:#111}}
h1{{margin-top:0;font-size:1.4rem}}
.card{{background:#fff;border:1px solid #ddd;border-radius:10px;padding:14px;margin-bottom:12px}}
.row{{display:flex;justify-content:space-between;gap:12px;padding:6px 0;border-bottom:1px solid #eee}}
.row:last-child{{border-bottom:none}}
.label{{color:#555}}.value{{font-weight:bold;text-align:right}}
pre{{white-space:pre-wrap;word-wrap:break-word;font-size:0.9rem;margin:0}}
.btn{{display:inline-block;padding:10px 14px;border-radius:8px;border:1px solid #111;text-decoration:none;color:#111;margin-right:8px}}
.small{{color:#666;font-size:0.9rem}}.section-title{{font-weight:bold;margin-bottom:8px}}
.err{{color:#a00;font-size:0.9rem;margin-top:6px}}
</style>
</head>
<body>
<h1>Helping Hand 01</h1>
<div class="small">AP: <b>{ssid}</b> &nbsp;|&nbsp; IP: <b>{ip}</b></div>
<div class="card">
  <div class="section-title">Status</div>
  <div class="row"><div class="label">RTC</div><div class="value" id="rtc">-</div></div>
  <div class="row"><div class="label">State</div><div class="value" id="state">-</div></div>
  <div class="row"><div class="label">Battery</div><div class="value" id="battery_v">-</div></div>
  <div class="row"><div class="label">Uptime</div><div class="value" id="uptime">-</div></div>
  <div class="row"><div class="label">Clients</div><div class="value" id="clients_connected">-</div></div>
</div>
<div class="card">
  <div class="section-title">Activity</div>
  <div class="row"><div class="label">Touches logged</div><div class="value" id="touch_count">-</div></div>
  <div class="row"><div class="label">Touches 24h</div><div class="value" id="touches_24h">-</div></div>
  <div class="row"><div class="label">Avg duration</div><div class="value" id="avg_touch_duration">-</div></div>
  <div class="row"><div class="label">Audio plays</div><div class="value" id="audio_play_count">-</div></div>
  <div class="row"><div class="label">Last touch</div><div class="value" id="last_touch_time">-</div></div>
</div>
<div class="card">
  <div class="section-title">Diagnostics</div>
  <div class="row"><div class="label">Ratio</div><div class="value" id="ratio">-</div></div>
  <div class="row"><div class="label">Buf rows</div><div class="value" id="buf">-</div></div>
  <div class="err" id="err"></div>
</div>
<div class="card">
  <a class="btn" href="/log.csv">Download CSV</a>
  <a class="btn" href="/" onclick="location.reload();return false;">Refresh</a>
</div>
<div class="card">
  <div class="section-title">Recent events</div>
  <pre id="recent">Connecting...</pre>
</div>
<script>
async function tick(){{
  try{{
    const r=await fetch('/api',{{cache:'no-store'}});
    if(!r.ok)throw new Error('HTTP '+r.status);
    const d=await r.json();
    document.getElementById('rtc').textContent=d.rtc;
    document.getElementById('state').textContent=d.state;
    document.getElementById('battery_v').textContent=d.battery_v+' V';
    document.getElementById('uptime').textContent=d.uptime;
    document.getElementById('clients_connected').textContent=d.clients_connected;
    document.getElementById('touch_count').textContent=d.touch_count;
    document.getElementById('touches_24h').textContent=d.touches_24h;
    document.getElementById('avg_touch_duration').textContent=d.avg_touch_duration;
    document.getElementById('audio_play_count').textContent=d.audio_play_count;
    document.getElementById('last_touch_time').textContent=d.last_touch_time;
    document.getElementById('ratio').textContent=d.ratio;
    document.getElementById('buf').textContent=d.buf_count;
    document.getElementById('recent').textContent=d.events.join('\\n')||'No events yet';
    document.getElementById('err').textContent='';
  }}catch(e){{document.getElementById('err').textContent='API error: '+e;}}
}}
tick();setInterval(tick,4000);
</script>
</body>
</html>
""".format(ssid=AP_SSID, ip=AP_IP)

# =========================================================
# HTTP HELPERS
# =========================================================

def socket_send_all(client, data):
    if isinstance(data, str):
        data = data.encode("utf-8")
    try:
        client.sendall(data)
        return
    except AttributeError:
        pass
    sent = 0
    total = len(data)
    while sent < total:
        n = client.send(data[sent:])
        if n is None or n <= 0:
            raise OSError("socket send failed")
        sent += n

def send_response(client, status="200 OK", content_type="text/plain", body="", extra_headers=None):
    if isinstance(body, str):
        body = body.encode("utf-8")
    headers = [
        "HTTP/1.1 {}".format(status),
        "Content-Type: {}".format(content_type),
        "Content-Length: {}".format(len(body)),
        "Connection: close",
        "Cache-Control: no-store",
    ]
    if extra_headers:
        headers.extend(extra_headers)
    socket_send_all(client, "\r\n".join(headers) + "\r\n\r\n")
    if body:
        socket_send_all(client, body)

def send_json(client, obj):
    send_response(client, "200 OK", "application/json", ujson.dumps(obj))

def send_csv_file(client, path):
    try:
        with open(path, "r") as f:
            body = f.read()
        send_response(client, "200 OK", "text/csv", body,
            extra_headers=['Content-Disposition: attachment; filename="touch_log.csv"'])
    except OSError:
        send_response(client, "500 Internal Server Error", "text/plain", "CSV read error")

def parse_path(req_text):
    try:
        first_line = req_text.split("\r\n", 1)[0]
        parts = first_line.split(" ")
        if len(parts) >= 2:
            path = parts[1]
            if path.startswith("http://") or path.startswith("https://"):
                slash = path.find("/", path.find("://") + 3)
                return path[slash:] if slash != -1 else "/"
            return path
    except Exception:
        pass
    return "/"

def build_api_payload(now_ms):
    ratio = (ema / base) if base else 0
    avg_touch_ms = get_avg_touch_duration_ms()
    return {
        "rtc": rtc_iso_string(),
        "state": get_state_string(playing, touch_active, armed),
        "battery_v": PLACEHOLDER_BATTERY_V,
        "uptime": format_uptime(ticks_diff(now_ms, BOOT)),
        "clients_connected": get_clients_connected(),
        "touch_count": touch_count,
        "touches_24h": get_touches_24h_display(),
        "avg_touch_duration": format_duration_ms(avg_touch_ms) if avg_touch_ms is not None else "N/A",
        "audio_play_count": audio_play_count,
        "last_touch_time": last_touch_time,
        "ratio": round(ratio, 3),
        "buf_count": _buf_count,
        "events": recent_events[-RECENT_EVENTS_MAX:],
    }

# =========================================================
# WIFI / AP SETUP
# =========================================================

ap = network.WLAN(network.AP_IF)
ap.active(True)
ap.config(essid=AP_SSID, password=AP_PASSWORD)
AP_IP = ap.ifconfig()[0]

server = socket.socket(socket.AF_INET, socket.SOCK_STREAM)
server.setsockopt(socket.SOL_SOCKET, socket.SO_REUSEADDR, 1)
server.bind(("0.0.0.0", HTTP_PORT))
server.listen(HTTP_BACKLOG)
server.settimeout(0.0)

# =========================================================
# STARTUP
# =========================================================

ensure_log_header()
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

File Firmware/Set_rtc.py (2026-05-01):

from machine import Pin, SoftI2C

I2C_SDA = 21
I2C_SCL = 22
RTC_ADDR = 0x68

i2c = SoftI2C(scl=Pin(I2C_SCL), sda=Pin(I2C_SDA), freq=100000)

def dec_to_bcd(d):
    return ((d // 10) << 4) | (d % 10)

def rtc_set_datetime(year, month, day, hour, minute, second, weekday=1):
    data = bytes([
        dec_to_bcd(second),
        dec_to_bcd(minute),
        dec_to_bcd(hour),
        dec_to_bcd(weekday),
        dec_to_bcd(day),
        dec_to_bcd(month),
        dec_to_bcd(year - 2000),
    ])
    i2c.writeto_mem(RTC_ADDR, 0x00, data)

# Set to: 2026-04-20 12:30:00
# weekday: 1-7 (DS3231 convention, not super important for your current code)
rtc_set_datetime(2026, 4, 30, 14, 53, 0, 4)

print("RTC set")
